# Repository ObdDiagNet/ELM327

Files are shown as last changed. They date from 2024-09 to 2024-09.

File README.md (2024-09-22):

ELM327 adapter and firmware based on PIC18F25K80
==========================================

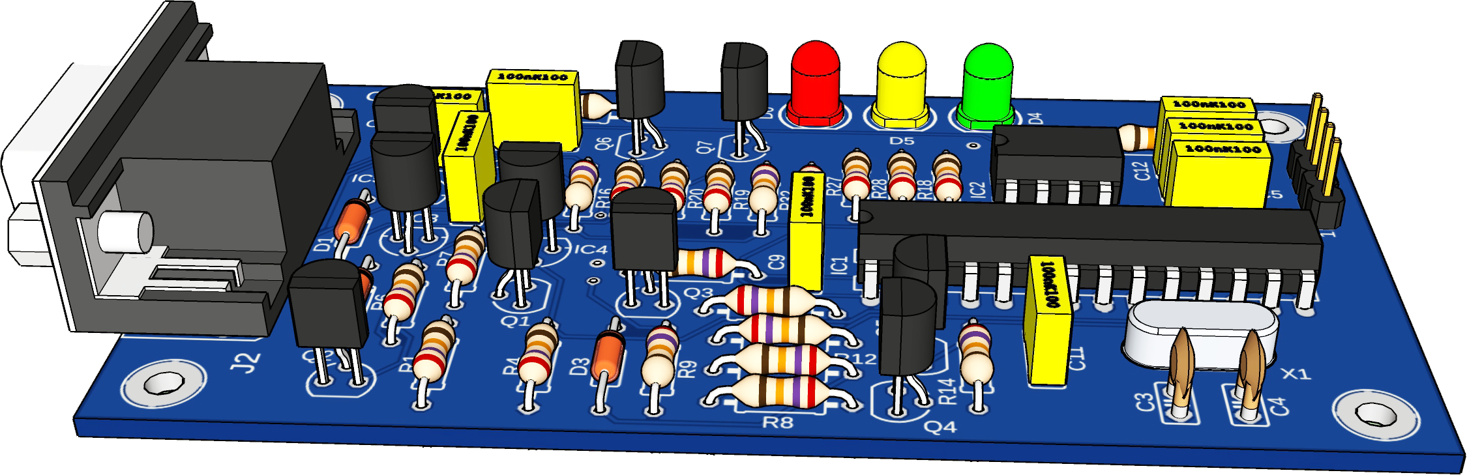
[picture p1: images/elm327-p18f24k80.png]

<p><b>You are always wanted to built ELM327 adapter but firmware was not available? Not anymore! Everything is here.</b>
This was a side project done for testing ELM327 firmware available openly on GitHub. I just wanted to see if it works. And yes, it is pretty much functional! When the original ELM327 based on PIC18F2480, this one is built around PIC18F25K80 chip. From the schematic prospective it is almost the same, the only difference is VCAP/VDDCORE decoupling capacitor C11 on pin 6.</p>
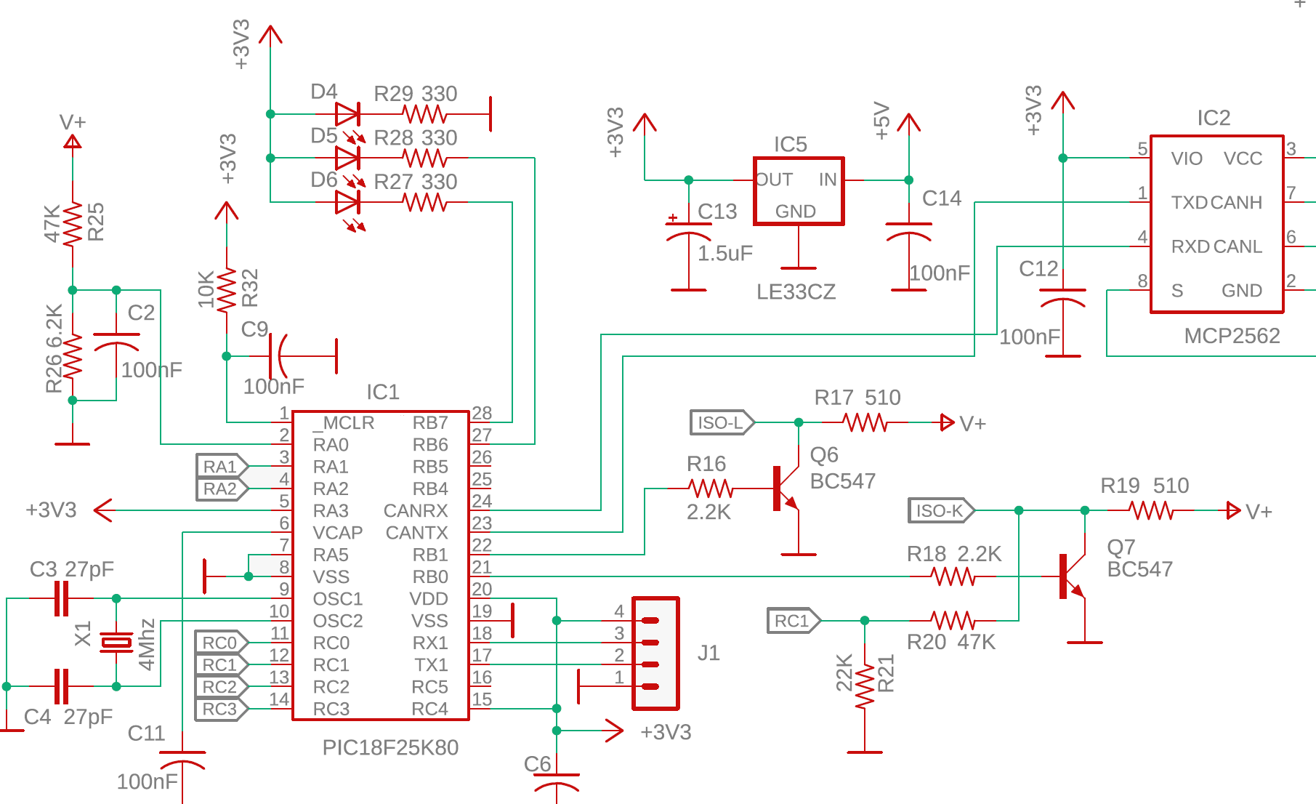
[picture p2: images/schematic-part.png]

<p>J1850 voltage regulator is simplified based on the fact that the logical voltage level is 3.3V vs. 5V for PIC18F2480. The adapter uses 9-pin D type female connector to link up to vehicle's OBD-II J1962 connector. The pinout is De-facto a standard for OBD cables. The cable available on eBay or AliExpress from many vendors. The printed circuit board layout is in Eagle 9 format.</p>
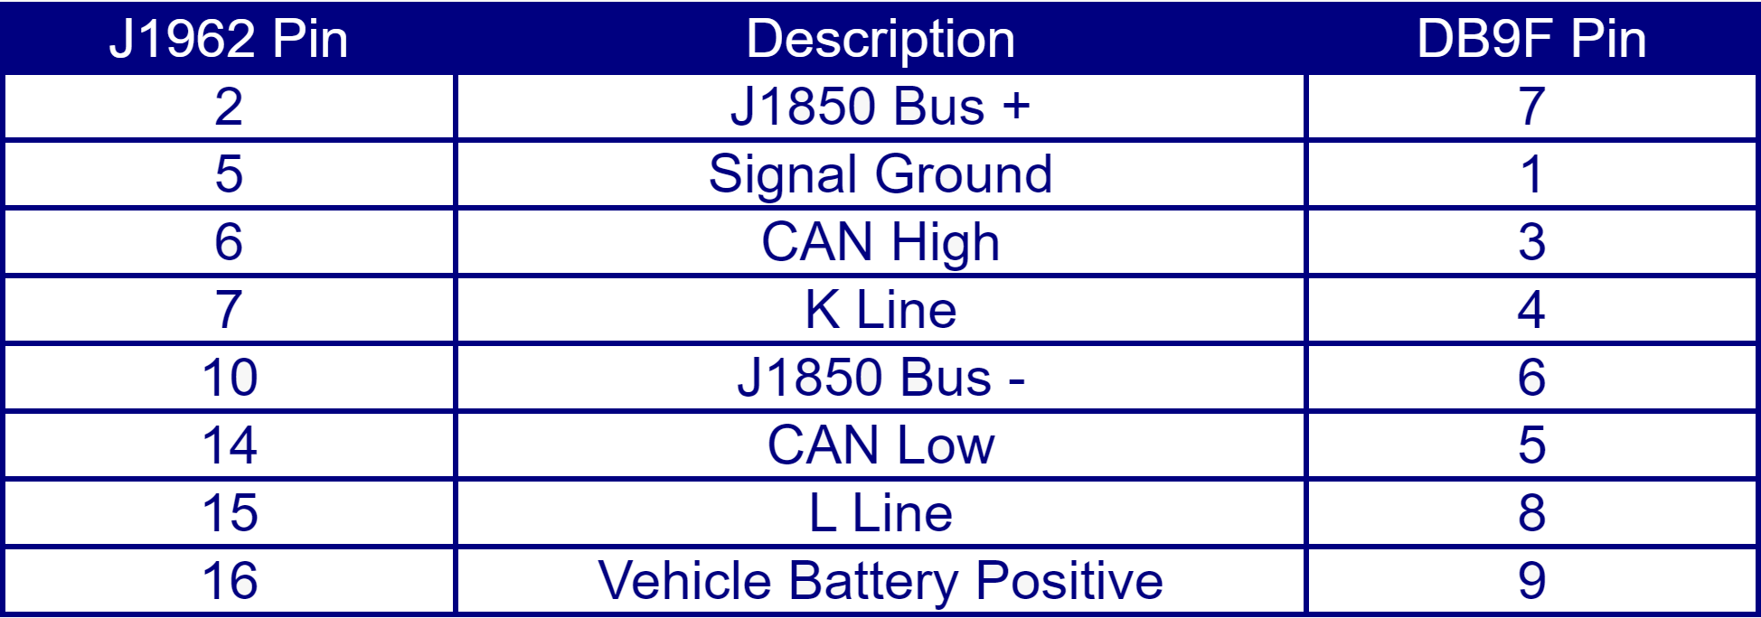
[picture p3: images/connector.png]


### Simplified schematic and improved firmware
One of many additional features of PIC18F25K80 is analog comparator. The previous schematic has comparator-like functionality with transistors Q4 and Q5. It can be replaced with PIC built-in analog comparator, see below. It should improve the reliability J1850 PWM signal handling. The firmware was modified as well to enable the internal comparator (the second in archive). Some unused pins turned to outputs, like RA3 and RC2. Using ULN2003 can reduce the number of external components. The Chinese knock-offs of ULN2003 are quite inexpensive. Another solution here to minimize number of components - using resistor arrays.
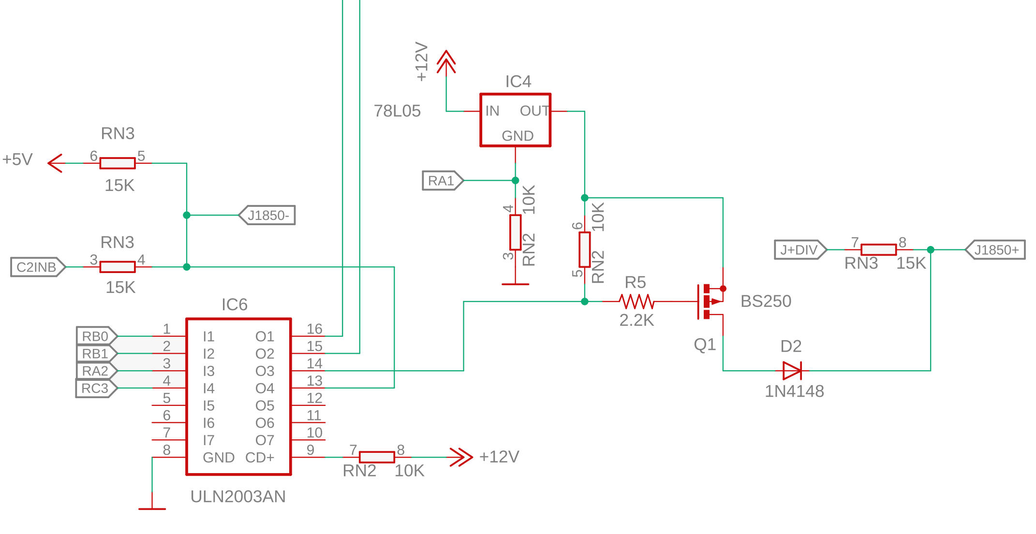
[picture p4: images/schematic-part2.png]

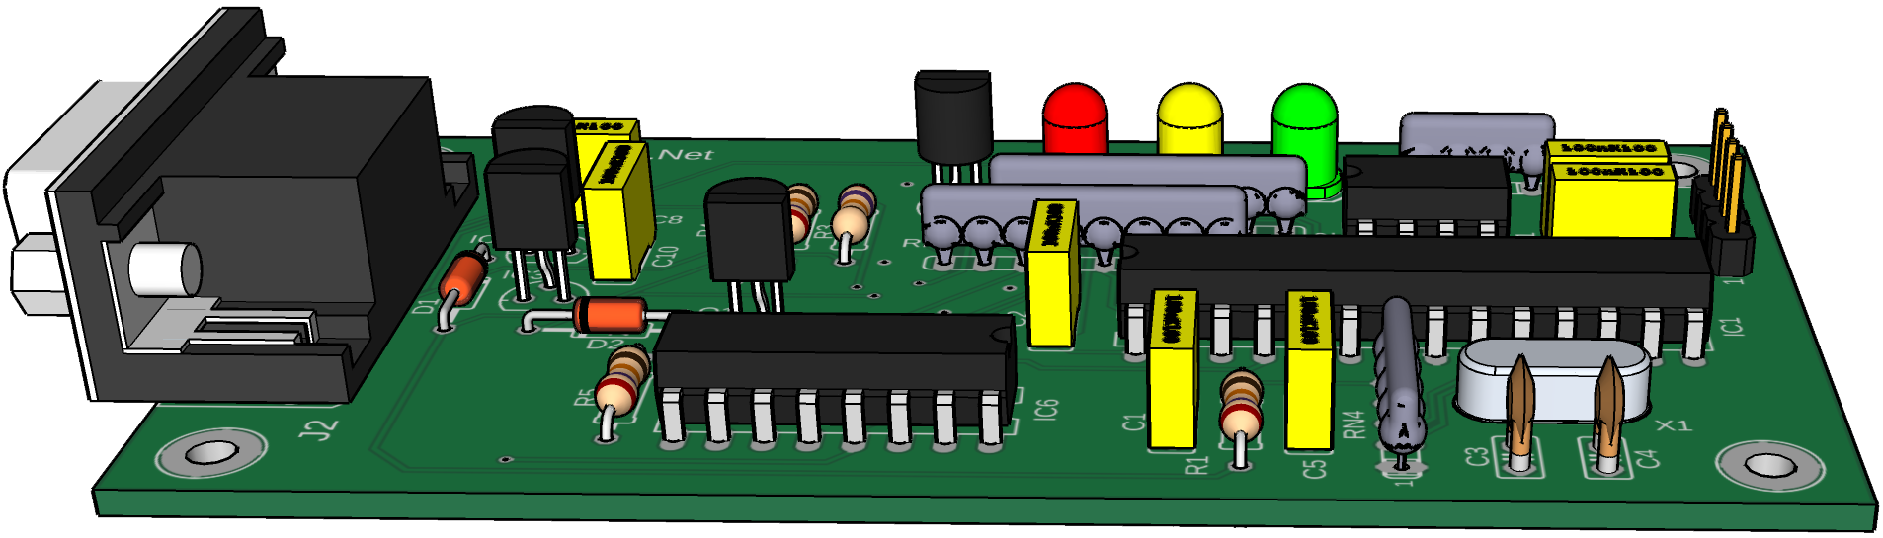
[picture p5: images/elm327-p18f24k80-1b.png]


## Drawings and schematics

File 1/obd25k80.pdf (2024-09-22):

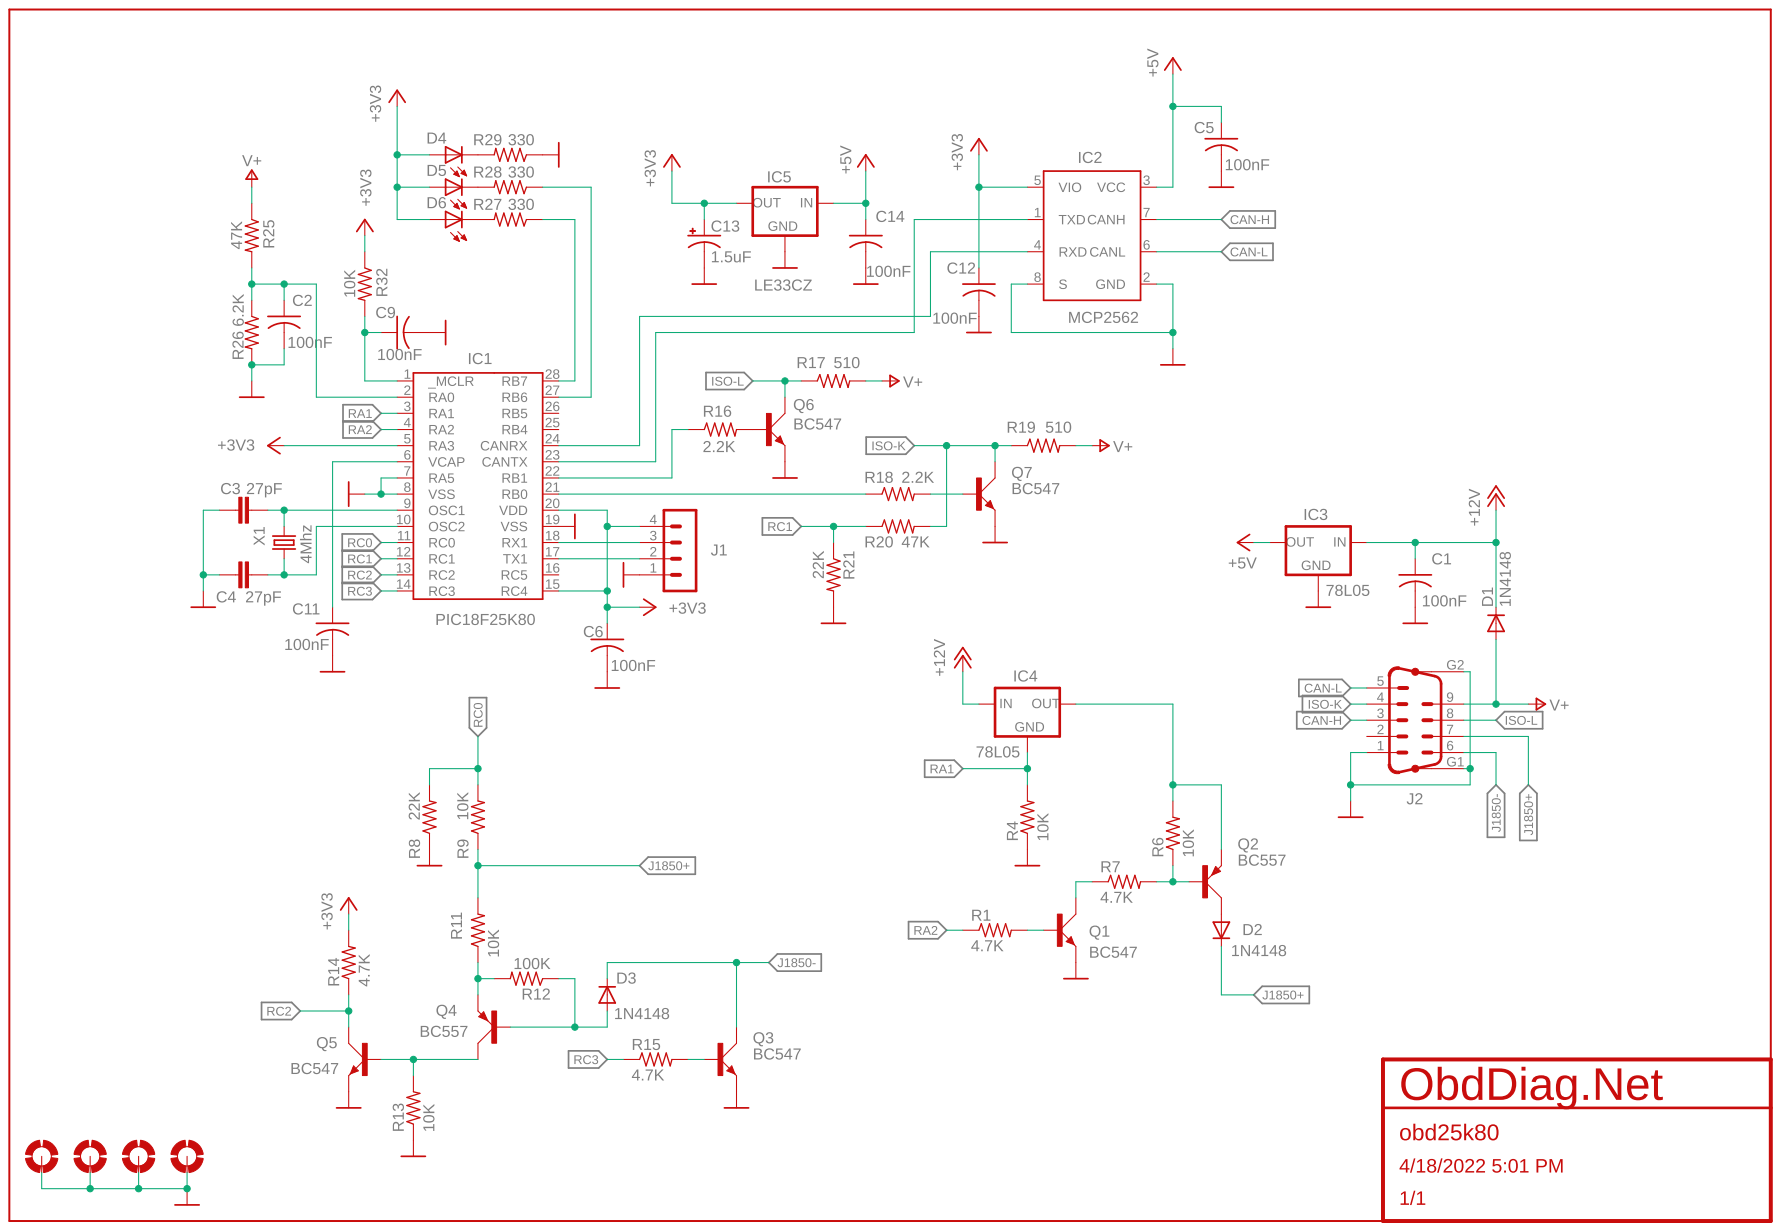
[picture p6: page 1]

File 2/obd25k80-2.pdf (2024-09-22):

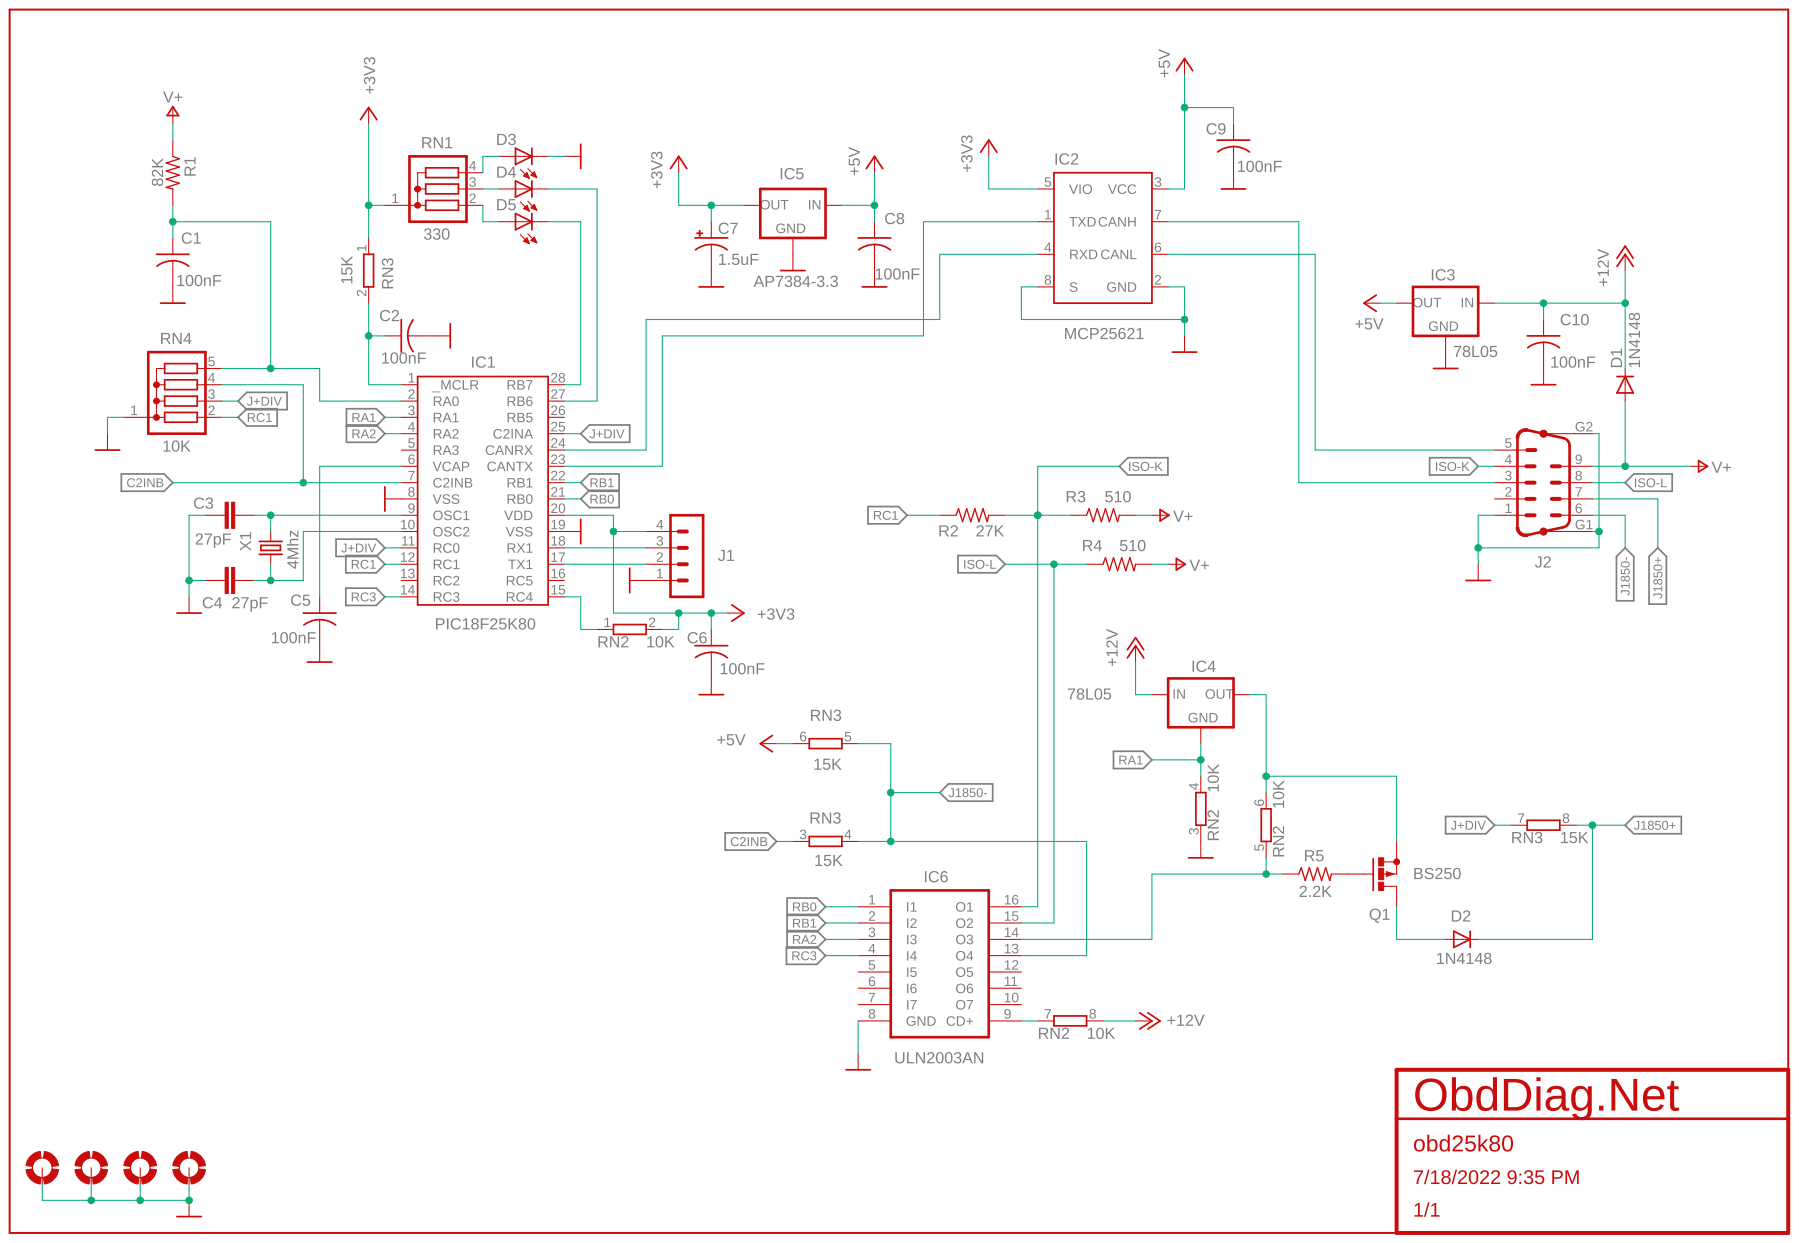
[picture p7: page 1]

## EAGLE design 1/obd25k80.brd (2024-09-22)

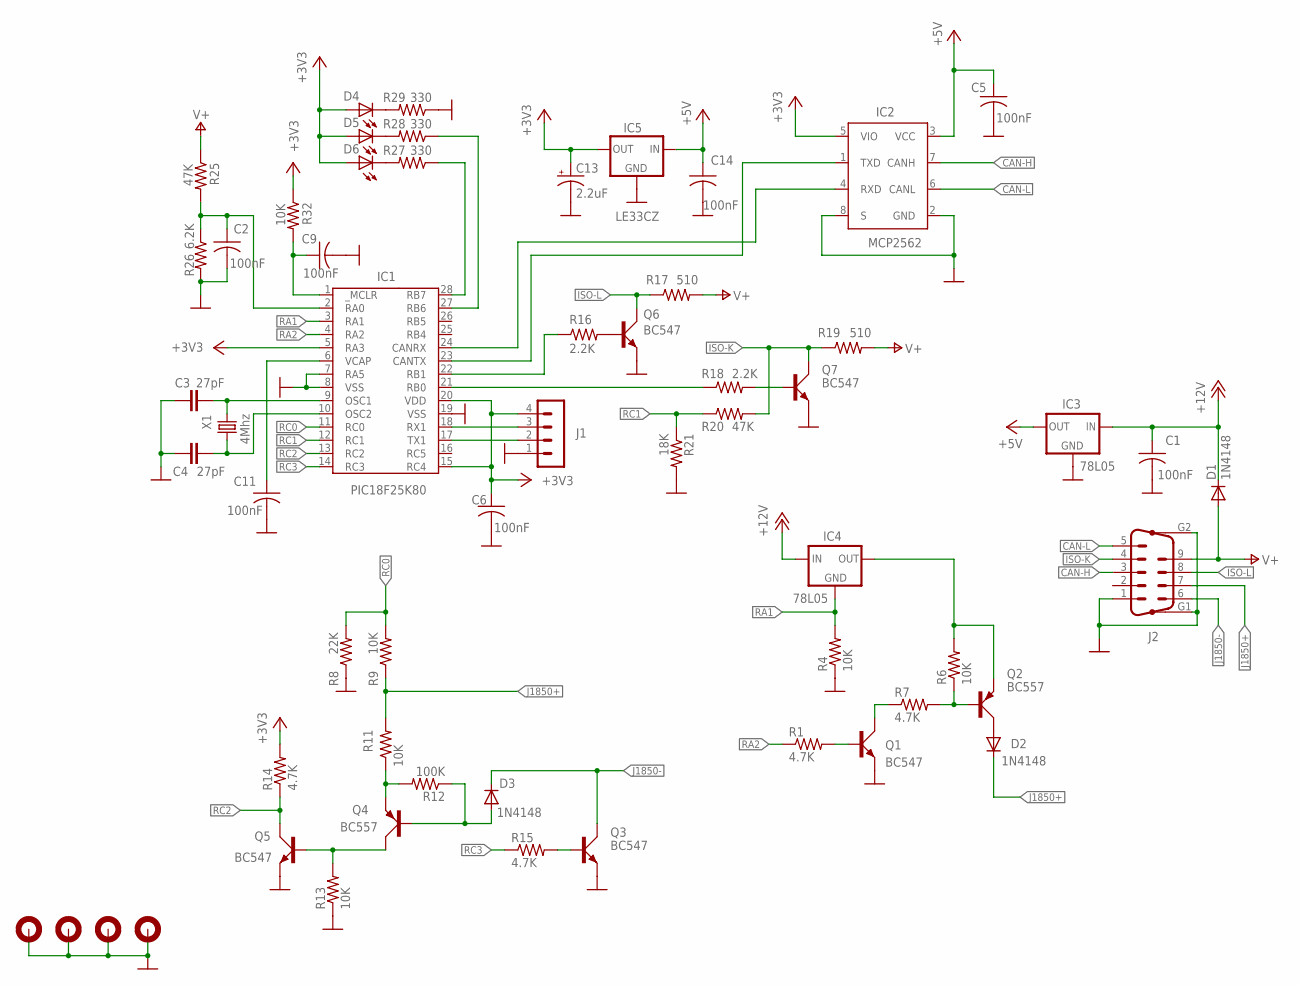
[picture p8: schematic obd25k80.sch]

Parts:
C1, C2, C5, C6, C9, C11, C14: 100nF; C050-025X075
C3, C4: 27pF; C2.5-2
C13: 2.2uF; E2,5-5
D1, D2, D3: 1N4148; D035-10M
D4, D5, D6: LED5MM
H1, H2, H3, H4: MOUNT-PAD-ROUND2.8; 2,8-PAD
IC1: PIC18F25K80; DIL28
IC2: MCP2562; DIL8
IC3, IC4: 78L05; 78LXX
IC5: LE33CZ; 78LXX
J1: MA04-1
J2: DB9-M; M09HP
Q1, Q3, Q5, Q6, Q7: BC547; SOT54A
Q2, Q4: BC557; SOT54A
R1, R7, R14, R15: 4.7K; 0207/10
R4, R6, R9, R11, R13, R32: 10K; 0207/10
R8: 22K; 0207/10
R12: 100K; 0207/10
R16, R18: 2.2K; 0207/10
R17, R19: 510; 0207/10
R20, R25: 47K; 0207/10
R21: 18K; 0207/10
R26: 6.2K; 0207/10
R27, R28, R29: 330; 0207/10
X1: 4Mhz; HC49/S

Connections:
+3V3: C6.1, C13.+, D4.A, D5.A, D6.A, IC1.5 (RA3), IC1.15 (RC4), IC1.20 (VDD), IC2.5 (VIO), IC5.OUT, J1.4, R14.2, R32.1
+5V: C5.1, C14.1, IC2.3 (VCC), IC3.OUT, IC5.IN
+12V: C1.1, D1.C, IC3.IN, IC4.IN
CAN-H: IC2.7 (CANH), J2.3
CAN-L: IC2.6 (CANL), J2.5
GND: C1.2, C2.2, C3.1, C4.2, C5.2, C6.2, C9.2, C11.2, C13.-, C14.2, H1.B2,8, H2.B2,8, H3.B2,8, H4.B2,8, IC1.7 (RA5), IC1.8 (VSS), IC1.19 (VSS), IC2.2 (GND), IC2.8 (S), IC3.GND, IC5.GND, J1.1, J2.1, J2.G1, J2.G2, Q1.E, Q3.E, Q5.E, Q6.E, Q7.E, R4.1, R8.1, R13.1, R21.2, R26.2, R29.1
ISO-K: J2.4, Q7.C, R19.1, R20.2
ISO-L: J2.8, Q6.C, R17.1
J1850+: D2.C, J2.7, R9.1, R11.2
J1850-: D3.C, J2.6, Q3.C
unnamed: D4.K (C), R29.2
unnamed: IC1.28 (RB7), R27.1
unnamed: D5.K (C), R28.2
unnamed: C9.1, IC1.1 (_MCLR), R32.2
unnamed: IC1.22 (RB1), R16.1
unnamed: D6.K (C), R27.2
unnamed: IC1.27 (RB6), R28.1
unnamed: C11.1, IC1.6 (VCAP)
unnamed: Q6.B, R16.2
unnamed: IC1.18 (RX1), J1.3
unnamed: IC1.24 (CANRX), IC2.4 (RXD)
unnamed: IC1.17 (TX1), J1.2
unnamed: IC1.21 (RB0), R18.1
unnamed: C3.2, IC1.9 (OSC1), X1.2
unnamed: Q3.B, R15.2
unnamed: IC1.23 (CANTX), IC2.1 (TXD)
unnamed: Q7.B, R18.2
unnamed: Q1.C, R7.1
unnamed: C2.1, IC1.2 (RA0), R25.2, R26.1
unnamed: Q1.B, R1.2
unnamed: Q2.B, R6.1, R7.2
unnamed: IC4.OUT, Q2.E, R6.2
unnamed: D2.A, Q2.C
unnamed: Q4.E, R11.1, R12.2
unnamed: D3.A, Q4.B, R12.1
unnamed: Q4.C, Q5.B, R13.2
unnamed: C4.1, IC1.10 (OSC2), X1.1
RA1: IC1.3 (RA1), IC4.GND, R4.2
RA2: IC1.4 (RA2), R1.1
RC0: IC1.11 (RC0), R8.2, R9.2
RC1: IC1.12 (RC1), R20.1, R21.1
RC2: IC1.13 (RC2), Q5.C, R14.1
RC3: IC1.14 (RC3), R15.1
V+: D1.A, J2.9, R17.2, R19.2, R25.1

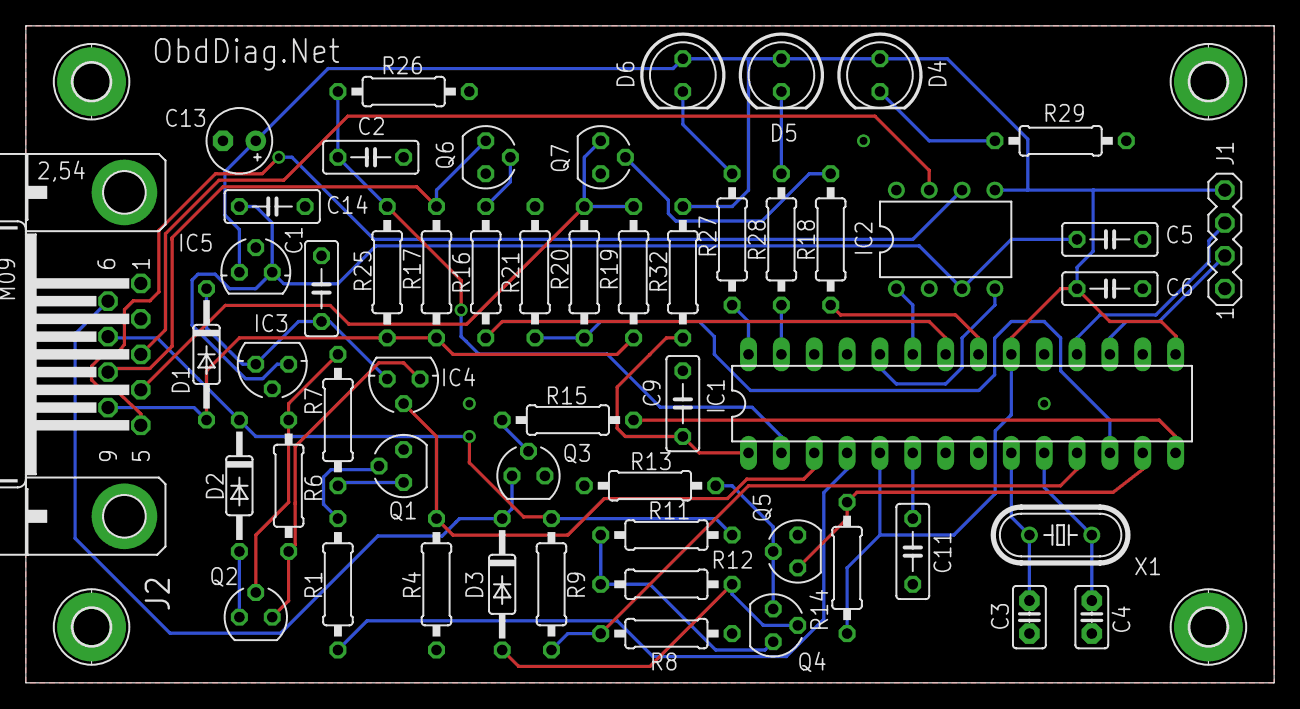
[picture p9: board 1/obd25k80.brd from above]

Board: 2 copper layers, 96.5 x 50.8 mm, 58 parts (0 on the bottom side), 44 nets.

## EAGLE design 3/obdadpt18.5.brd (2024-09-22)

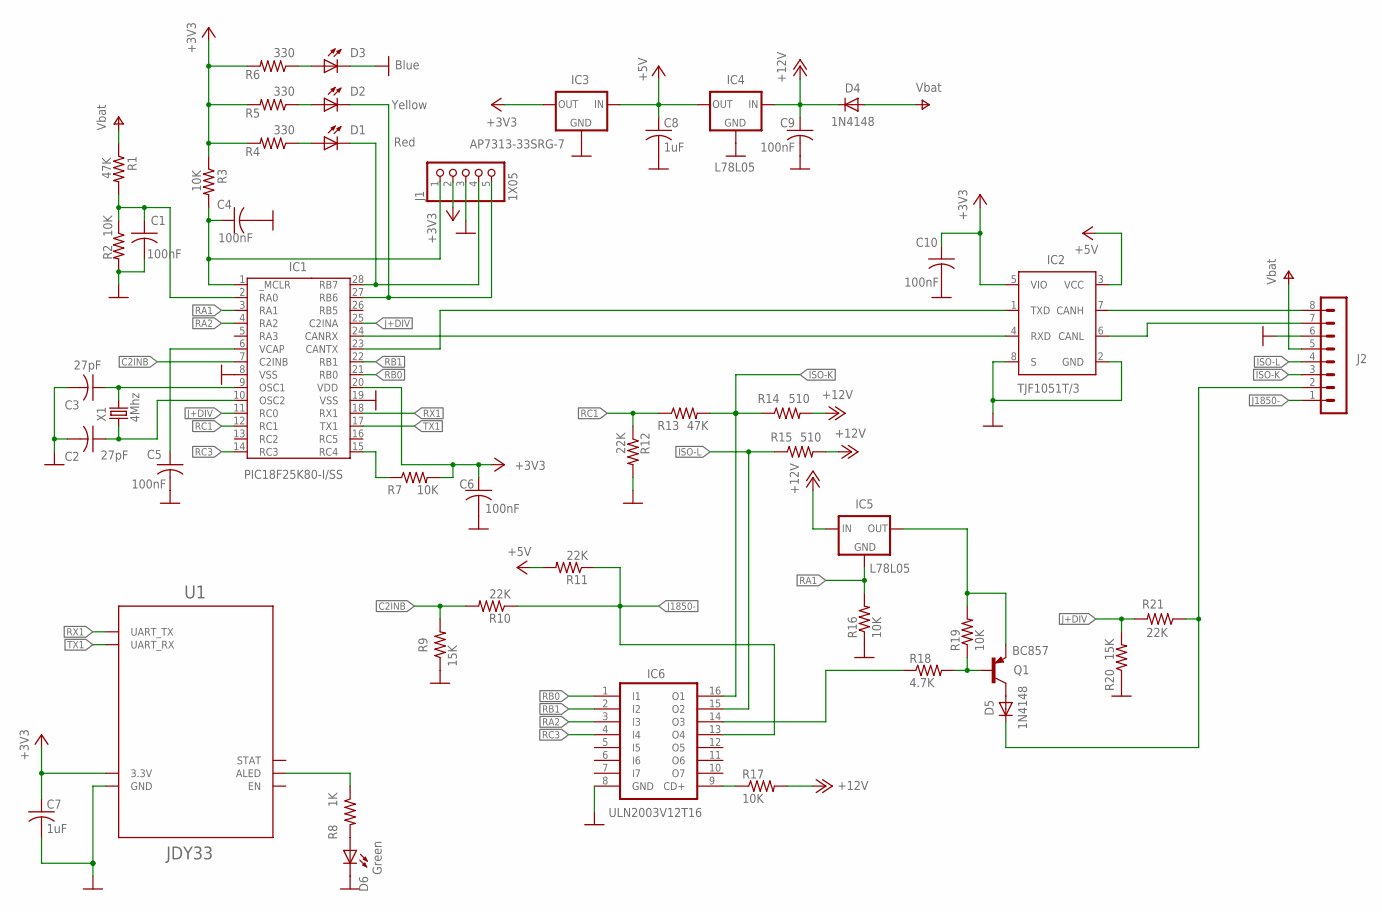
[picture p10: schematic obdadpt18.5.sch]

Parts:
C1, C4, C5, C6, C9, C10: 100nF; C0805
C2, C3: 27pF; C0805
C7, C8: 1uF; C0805
D1: Red; CHIPLED_0805
D2: Yellow; CHIPLED_0805
D3: Blue; CHIPLED_0805
D4, D5: 1N4148; SOD123
D6: Green; CHIPLED_0805
IC1: PIC18F25K80-I/SS; SSOP28DB
IC2: TJF1051T/3; SO-8
IC3: AP7313-33SRG-7; SOT23
IC4, IC5: L78L05; SOT89R
IC6: ULN2003V12T16; TSSOP16
J1: 1X05
J2: MA08-1
Q1: BC857; SOT23-BEC
R1, R13: 47K; R0805
R2, R3, R7, R16, R17, R19: 10K; R0805
R4, R5, R6: 330; R0805
R8: 1K; R0805
R9, R20: 15K; R0805
R10, R11, R12, R21: 22K; R0805
R14, R15: 510; R1206
R18: 4.7K; R0805
U1: JDY33
X1: 4Mhz; SM49

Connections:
+3V3: C6.1, C7.1, C10.1, IC1.20 (VDD), IC2.5 (VIO), IC3.2 (OUT), J1.2, R3.1, R4.2, R5.2, R6.2, R7.2, U1.12 (3.3V)
+5V: C8.1, IC2.3 (VCC), IC3.3 (IN), IC4.2 (OUT), R11.2
+12V: C9.1, D4.C, IC4.1 (IN), IC5.1 (IN), R14.2, R15.2, R17.2
C2INB: IC1.7 (C2INB), R9.2, R10.2
CAN-H: IC2.7 (CANH), J2.8
CAN-L: IC2.6 (CANL), J2.7
GND: C1.2, C2.2, C3.2, C4.2, C5.2, C6.2, C7.2, C8.2, C9.2, C10.2, D3.C, D6.C, IC1.8 (VSS), IC1.19 (VSS), IC2.2 (GND), IC2.8 (S), IC3.1 (GND), IC4.4 (GND), IC6.8 (GND), J1.3, J2.6, R2.2, R9.1, R12.2, R16.1, R20.1, U1.13 (GND)
ISO-K: IC6.16 (O1), J2.3, R13.2, R14.1
ISO-L: IC6.15 (O2), J2.4, R15.1
J1850+: D5.C, J2.2, R21.1
J1850-: IC6.13 (O4), J2.1, R10.1, R11.1
J+DIV: IC1.11 (RC0), IC1.25 (C2INA), R20.2, R21.2
unnamed: D6.A, R8.2
unnamed: D5.A, Q1.C
unnamed: D1.A, R4.1
unnamed: R8.1, U1.16 (ALED)
unnamed: D1.C, IC1.28 (RB7), J1.4
unnamed: D2.A, R5.1
unnamed: D3.A, R6.1
unnamed: D2.C, IC1.27 (RB6), J1.5
unnamed: IC1.24 (CANRX), IC2.4 (RXD)
unnamed: C5.1, IC1.6 (VCAP)
unnamed: C4.1, IC1.1 (_MCLR), J1.1, R3.2
unnamed: IC1.15 (RC4), R7.1
unnamed: C3.1, IC1.9 (OSC1), X1.1
unnamed: IC6.9 (CD+), R17.1
unnamed: IC1.23 (CANTX), IC2.1 (TXD)
unnamed: IC6.14 (O3), R18.1
unnamed: C1.1, IC1.2 (RA0), R1.2, R2.1
unnamed: Q1.B, R18.2, R19.1
unnamed: IC5.2 (OUT), Q1.E, R19.2
unnamed: C2.1, IC1.10 (OSC2), X1.2
RA1: IC1.3 (RA1), IC5.4 (GND), R16.2
RA2: IC1.4 (RA2), IC6.3 (I3)
RB0: IC1.21 (RB0), IC6.1 (I1)
RB1: IC1.22 (RB1), IC6.2 (I2)
RC1: IC1.12 (RC1), R12.1, R13.1
RC3: IC1.14 (RC3), IC6.4 (I4)
RX1: IC1.18 (RX1), U1.1 (UART_TX)
TX1: IC1.17 (TX1), U1.2 (UART_RX)
V+: D4.A, J2.5, R1.1

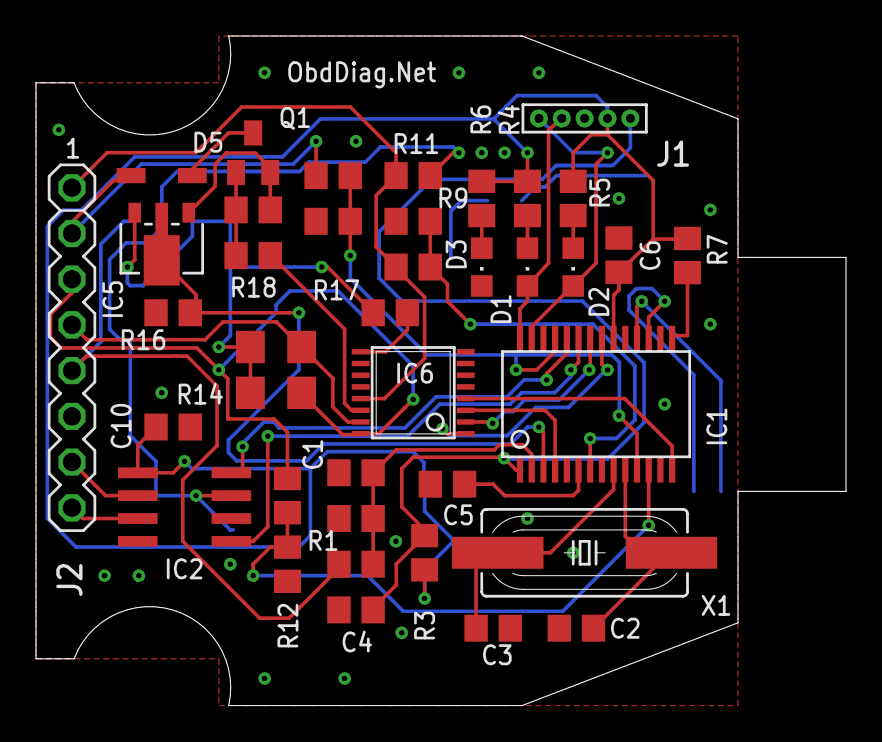
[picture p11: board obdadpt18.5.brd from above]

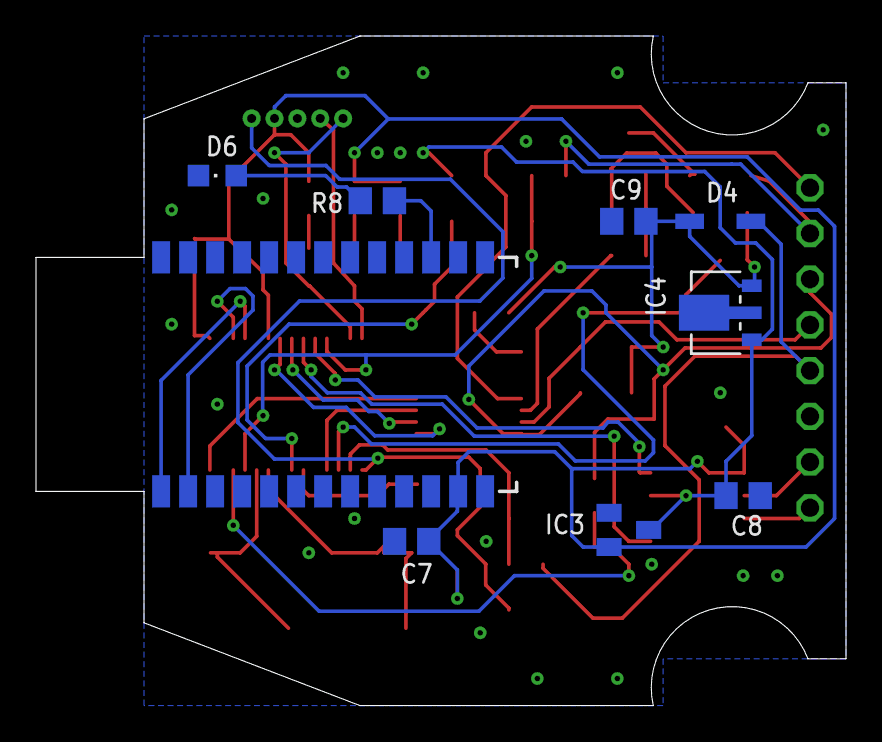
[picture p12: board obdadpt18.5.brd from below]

Board: 2 copper layers, 45.0 x 37.2 mm, 48 parts (9 on the bottom side), 41 nets.

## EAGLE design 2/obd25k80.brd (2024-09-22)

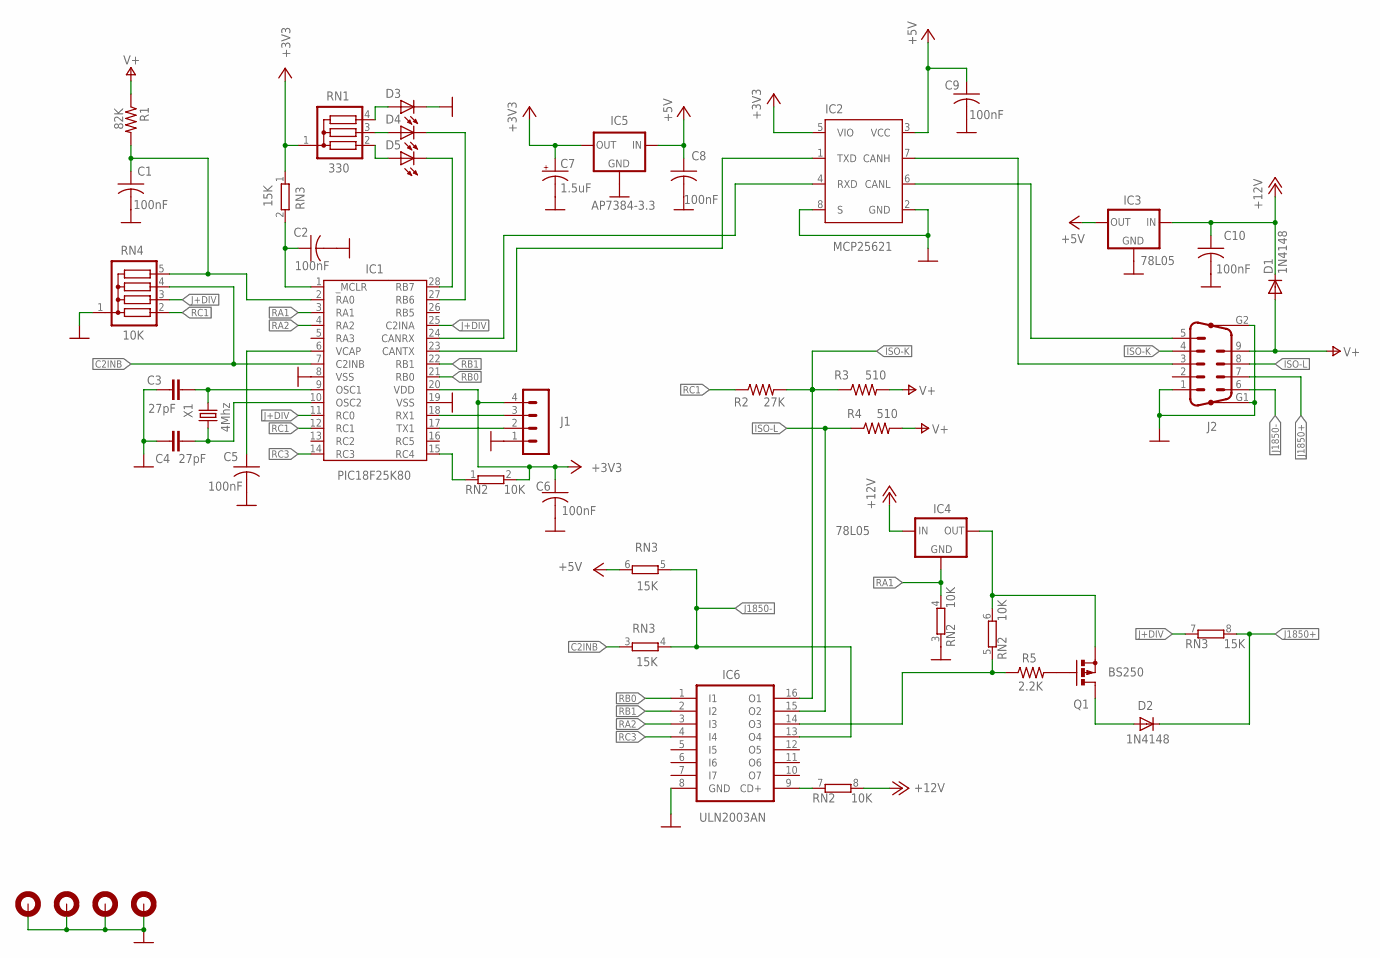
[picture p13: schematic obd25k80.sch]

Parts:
C1, C2, C5, C6, C8, C9, C10: 100nF; C050-025X075
C3, C4: 27pF; C2.5-2
C7: 1.5uF; E2,5-5
D1, D2: 1N4148; D035-10M
D3, D4, D5: LED5MM
H1, H2, H3, H4: MOUNT-PAD-ROUND2.8; 2,8-PAD
IC1: PIC18F25K80; DIL28
IC2: MCP25621; DIL8
IC3, IC4: 78L05; 78LXX
IC5: AP7384-3.3; TO92
IC6: ULN2003AN; DIL16
J1: MA04-1
J2: DB9-M; M09HP
Q1: BS250; SOT54E
R1: 82K; 0207/10
R2: 27K; 0207/10
R3, R4: 510; 0207/10
R5: 2.2K; 0207/10
RN1: 330; SIL4
RN2: 10K; SIL8
RN3: 15K; SIL8
RN4: 10K; SIL5
X1: 4Mhz; HC49/S

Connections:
+3V3: C6.1, C7.+, IC1.20 (VDD), IC2.5 (VIO), IC5.3 (OUT), J1.4, RN1.1, RN2.2, RN3.1
+5V: C8.1, C9.1, IC2.3 (VCC), IC3.OUT, IC5.1 (IN), RN3.6 (2)
+12V: C10.1, D1.C, IC3.IN, IC4.IN, RN2.8 (2)
C2INB: IC1.7 (C2INB), RN3.3 (1), RN4.4
CAN-H: IC2.7 (CANH), J2.3
CAN-L: IC2.6 (CANL), J2.5
GND: C1.2, C2.2, C3.1, C4.2, C5.2, C6.2, C7.-, C8.2, C9.2, C10.2, D3.K (C), H1.B2,8, H2.B2,8, H3.B2,8, H4.B2,8, IC1.8 (VSS), IC1.19 (VSS), IC2.2 (GND), IC2.8 (S), IC3.GND, IC5.2 (GND), IC6.8 (GND), J1.1, J2.1, J2.G1, J2.G2, RN2.3 (1), RN4.1
ISO-K: IC6.16 (O1), J2.4, R2.2, R3.1
ISO-L: IC6.15 (O2), J2.8, R4.1
J1850+: D2.C, J2.7, RN3.8 (2)
J1850-: IC6.13 (O4), J2.6, RN3.4 (2), RN3.5 (1)
J+DIV: IC1.11 (RC0), IC1.25 (C2INA), RN3.7 (1), RN4.3
unnamed: D5.A, RN1.2
unnamed: D5.K (C), IC1.28 (RB7)
unnamed: IC1.15 (RC4), RN2.1
unnamed: IC6.9 (CD+), RN2.7 (1)
unnamed: D4.A, RN1.3
unnamed: D3.A, RN1.4
unnamed: C2.1, IC1.1 (_MCLR), RN3.2
unnamed: D2.A, Q1.D
unnamed: C1.1, IC1.2 (RA0), R1.2, RN4.5
unnamed: Q1.G, R5.2
unnamed: D4.K (C), IC1.27 (RB6)
unnamed: C5.1, IC1.6 (VCAP)
unnamed: IC1.18 (RX1), J1.3
unnamed: IC1.24 (CANRX), IC2.4 (RXD)
unnamed: IC1.17 (TX1), J1.2
unnamed: C3.2, IC1.9 (OSC1), X1.2
unnamed: IC1.23 (CANTX), IC2.1 (TXD)
unnamed: IC6.14 (O3), R5.1, RN2.5 (1)
unnamed: IC4.OUT, Q1.S, RN2.6 (2)
unnamed: C4.1, IC1.10 (OSC2), X1.1
RA1: IC1.3 (RA1), IC4.GND, RN2.4 (2)
RA2: IC1.4 (RA2), IC6.3 (I3)
RB0: IC1.21 (RB0), IC6.1 (I1)
RB1: IC1.22 (RB1), IC6.2 (I2)
RC1: IC1.12 (RC1), R2.1, RN4.2
RC3: IC1.14 (RC3), IC6.4 (I4)
V+: D1.A, J2.9, R1.1, R3.2, R4.2

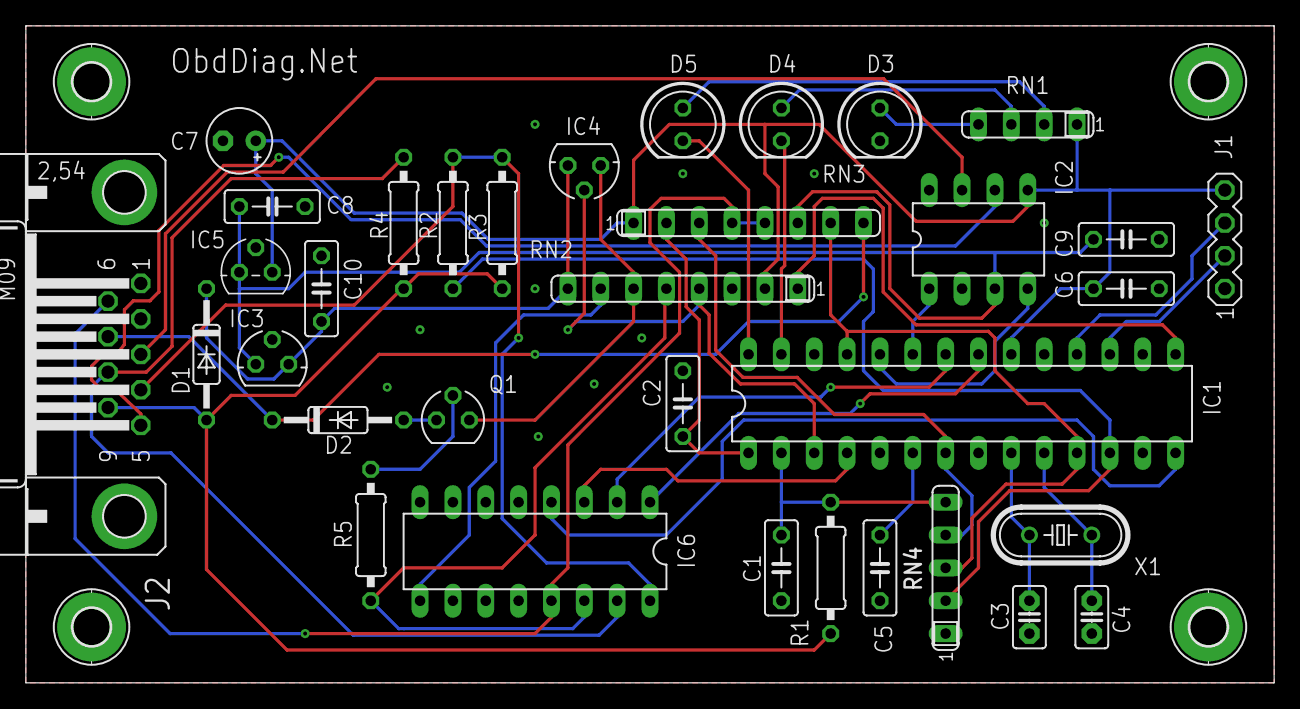
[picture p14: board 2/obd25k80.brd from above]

Board: 2 copper layers, 96.5 x 50.8 mm, 38 parts (0 on the bottom side), 39 nets.
